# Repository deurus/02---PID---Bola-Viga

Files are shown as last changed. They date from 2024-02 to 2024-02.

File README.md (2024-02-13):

# Bola Viga

La maqueta está realizada con piezas impresas en 3D para la ocasión y un par de varillas metálicas por donde se desliza la bola.

El funcionamiento es muy sencillo, disponemos de un micro interruptor para cambiar entre modo manual y automático, y de un potenciómetro que en modo manual mueve el ángulo del servo y por ende la inclinación de la viga (OP), y en modo automático cambia el punto de consigna (SP) de posición de la bola en la viga. El objetivo es situar una bola en una posición determinada de la viga mediante un controlador PID.

<p align="center">
  esquema
</p>

Investigando un poco que tipo de sensores de distancia asequibles existen para Arduino, encontré unos cuantos y muchos ejemplos de uso, pero es diferente cuando se hace una prueba de un sensor a cuando le das un uso en el que se requiere cierta precisión. De todo lo que encontré me quedo con cuatro sensores de los que os dejo una tabla comparativa.

<p align="center">
  esquema
</p>

Tenéis más información en la entrada del blog: https://garikoitz.info/blog/2021/09/sintonizar-pid-con-arduino-sistema-bola-viga/

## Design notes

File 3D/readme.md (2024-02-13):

Los archivos 3D originales han sido creados por Henar Brenlla para su proyecto fin de grado que podéis encontrar aquí: [https://github.com/HenarB/controldedistanciapelota]

Autor: Henar Brenlla <br>
01 BASE SENSOR <br>		
02 BASE SERVO MOTOR <br>	
03 DISCO RANURADO <br>	
04 MANIVELA <br>	
05 SOPORTE SENSOR GP2Y0A21YK0F <br>
06 SOPORTE <br>

Autor: garikoitz.info <br>
05 SOPORTE SENSOR VL53L0X (Modificación para el sensor VL53L0X y varillas de otro diámetro)<br>
06 SOPORTE_v2 (Modificación del soporte original para varillas de otro diámetro)<br>

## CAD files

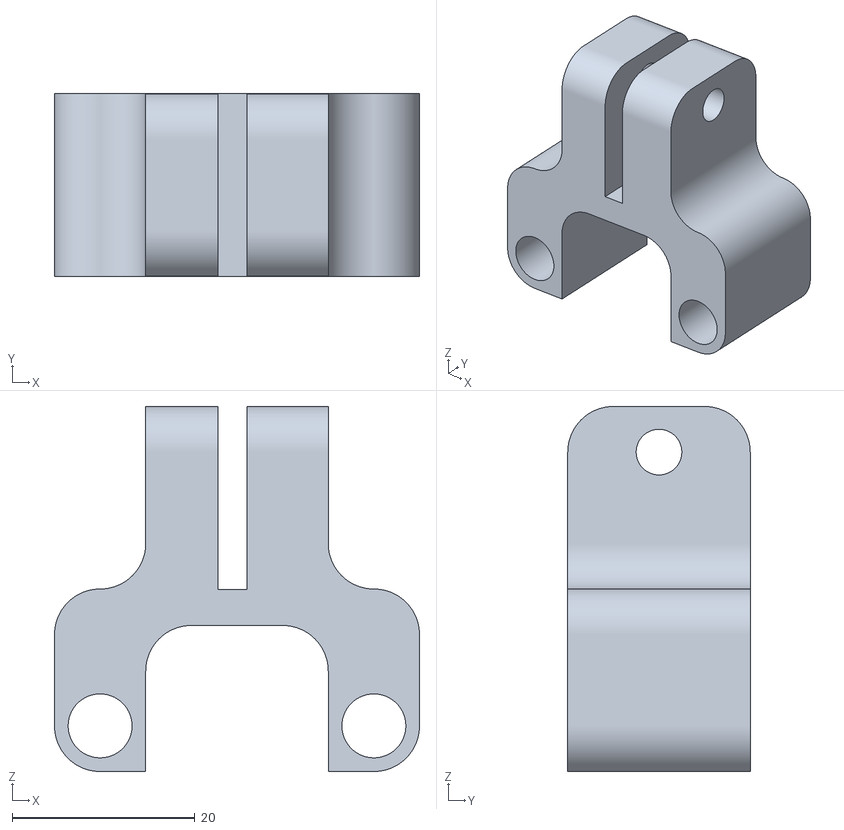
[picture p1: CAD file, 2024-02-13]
3D/06 SOPORTE_v3 (garikoitz).stl
40.0 x 20.0 x 40.0

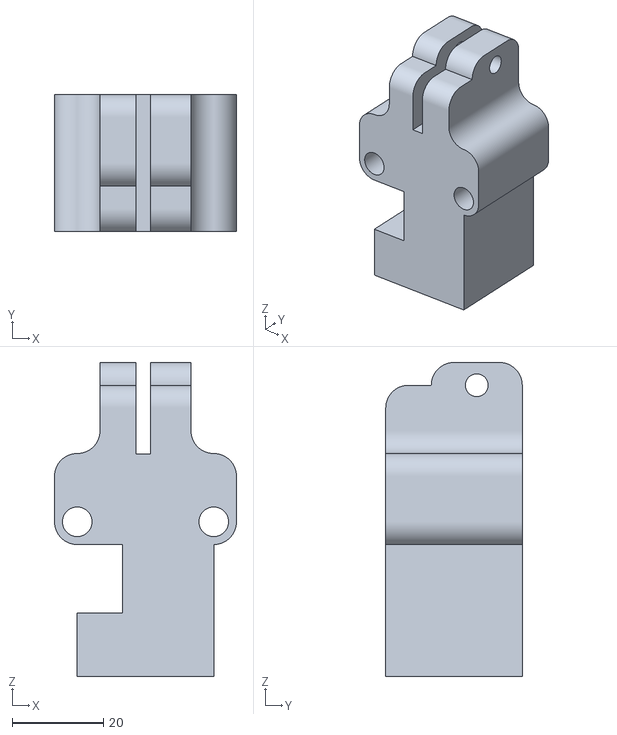
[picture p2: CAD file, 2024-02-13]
3D/05 SOPORTE SENSOR US-016_vertival_ (garikoitz).stl
40.0 x 30.0 x 69.0

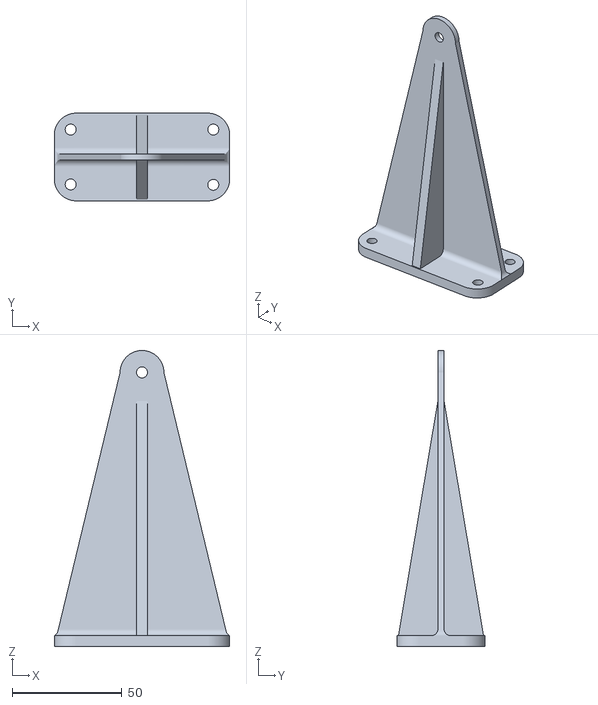
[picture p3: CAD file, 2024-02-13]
3D/01 BASE SENSOR.stl
80.0 x 40.0 x 135.0

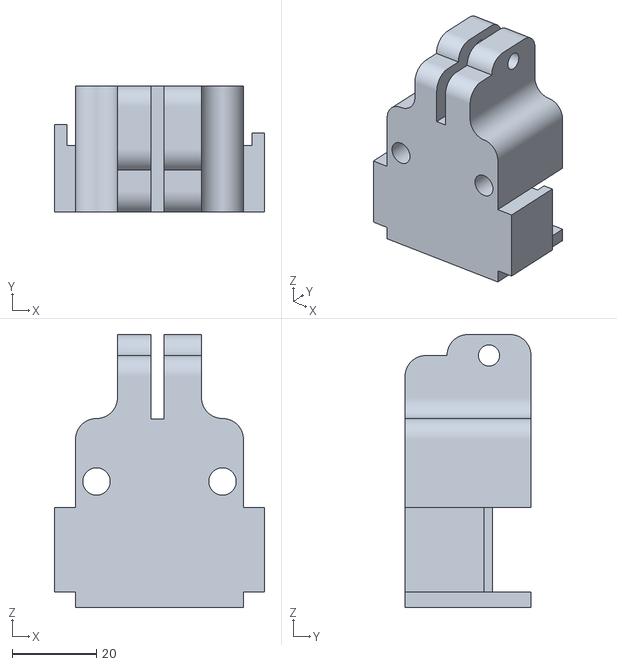
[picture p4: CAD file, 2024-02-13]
3D/05 SOPORTE SENSOR US-016_horizontal (garikoitz).stl
50.0 x 30.0 x 65.0

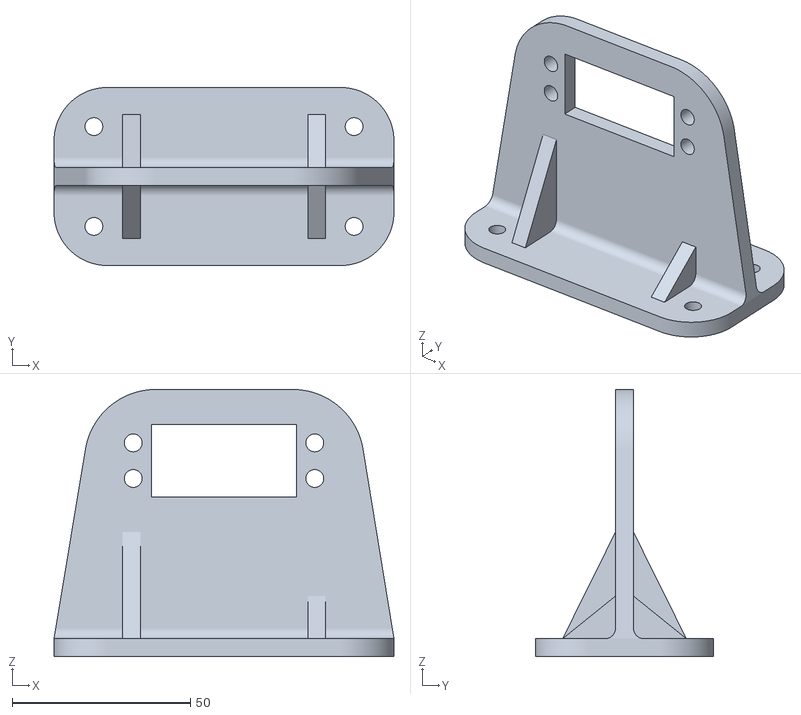
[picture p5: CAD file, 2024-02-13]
3D/02 BASE SERVO MOTOR.stl
95.5 x 50.0 x 75.0

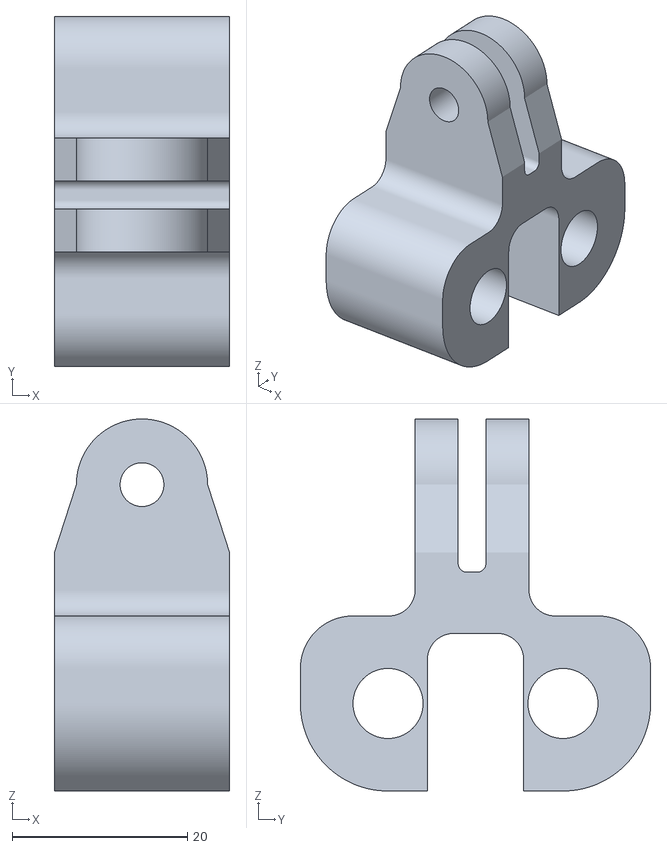
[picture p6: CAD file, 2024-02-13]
3D/06 SOPORTE.stl
20.0 x 40.0 x 42.5

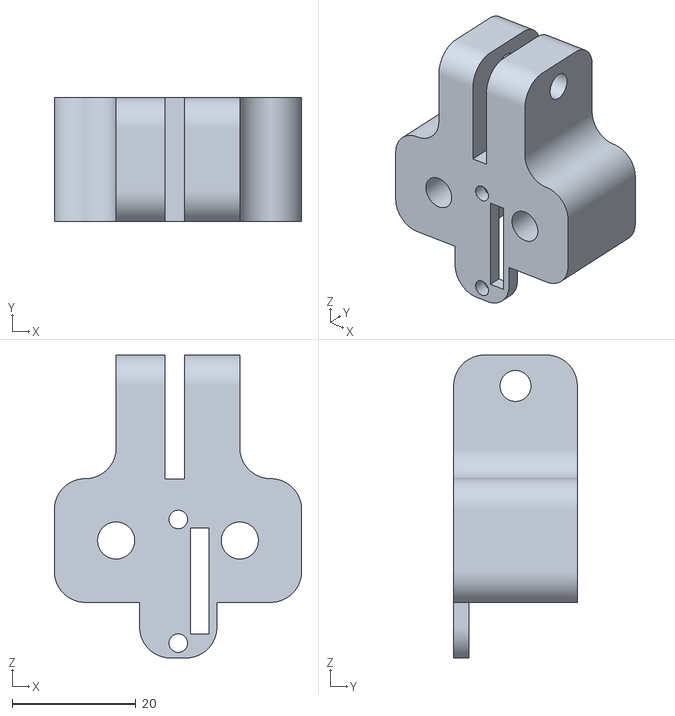
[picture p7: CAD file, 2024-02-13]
3D/05 SOPORTE SENSOR VL53L0X (garikoitz).stl
40.0 x 20.0 x 49.0

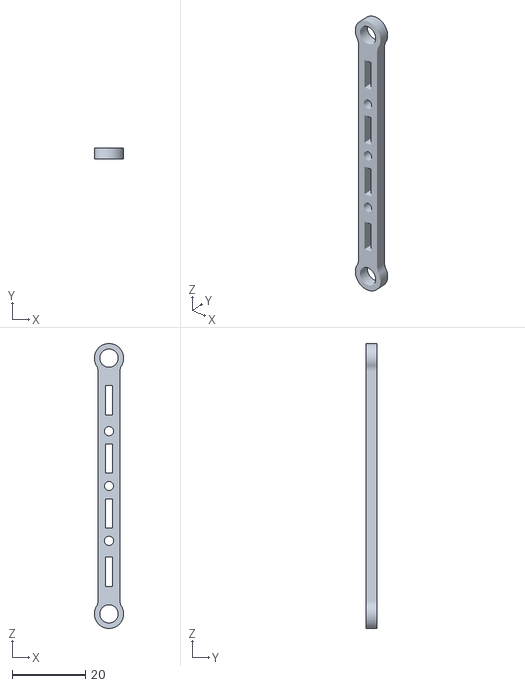
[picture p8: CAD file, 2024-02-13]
3D/04 MANIVELA.stl
8.00 x 3.00 x 78.0

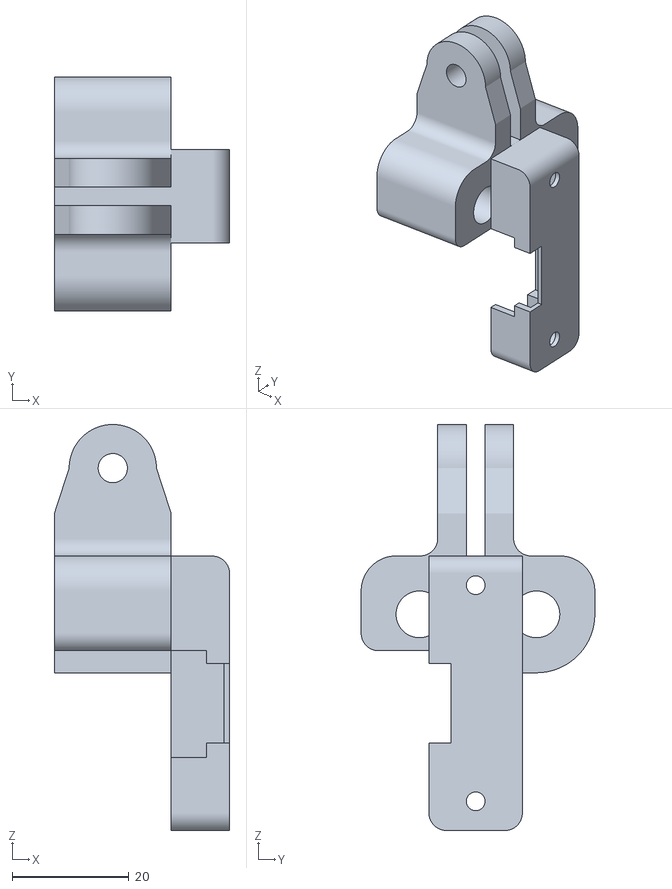
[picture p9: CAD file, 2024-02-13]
3D/05 SOPORTE SENSOR GP2Y0A21YK0F.stl
30.0 x 40.0 x 69.5

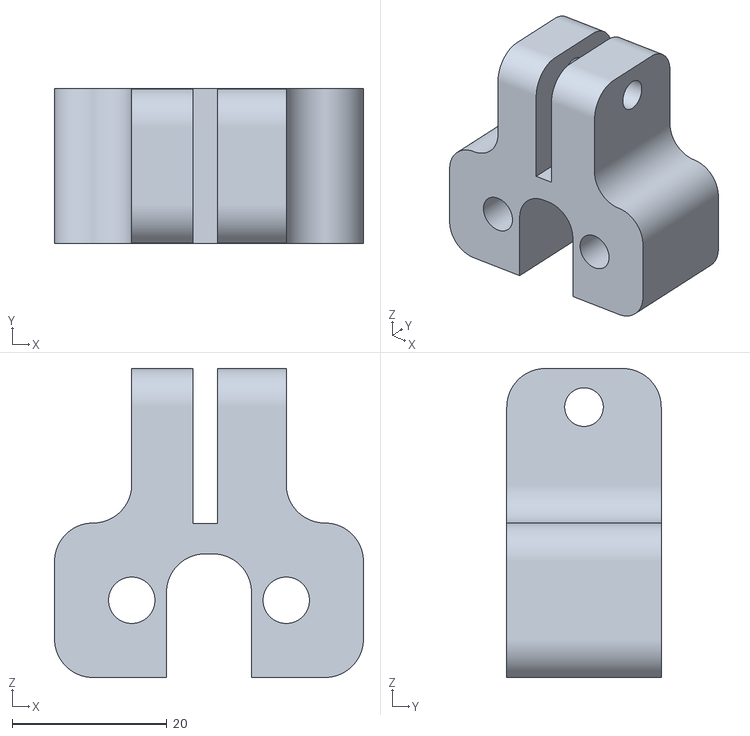
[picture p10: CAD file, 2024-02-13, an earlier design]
3D/06 SOPORTE_v2 (garikoitz).stl
40.0 x 20.0 x 40.0

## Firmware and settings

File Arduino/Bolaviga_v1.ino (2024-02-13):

/***************************************************************
* Desarrollado por Garikoitz Martínez [garikoitz.info] [06/2022]
* https://garikoitz.info/blog/?p=1301
***************************************************************/
/***************************************************************
* Librerías
***************************************************************/
#include <Wire.h>
#include <PID_v1.h>
#include "Adafruit_VL53L0X.h"
#include <Servo.h>
/***************************************************************
* Variables
***************************************************************/
Servo myservo;
const int Interruptor = 12;
unsigned long previousMillis = 0; 
int Ts = 50, pos = 0;
unsigned long contador = 0; 
//Control PID
boolean modo = false;                       //false=auto true=manual
float tmp=0.0, tmp_ant=0.0, OP=0, angulo=0.0, angulo_ant=0.0, media=0.0;
double SetpointP, InputP, OutputP;
/***************************************************************
* Sintonías calculadas (Relé --> Ku=0.99 y Tu=4.6 segundos)
***************************************************************/
//double Kc=0.59, Ki=0.26, Kd=0.34;   //Z-N classic PID
//double Kc=0.69, Ki=0.38, Kd=0.48;   //Z-N Pessen Integral Rule 
//double Kc=0.33, Ki=0.14, Kd=0.49;   //Z-N some overshoot
//double Kc=0.20, Ki=0.09, Kd=0.30;   //Z-N no overshoot
//double Kc=0.33, Ki=0.07, Kd=0.15;    //Farrington
//double Kc=0.49, Ki=0.11, Kd=0.57;    //Farrington
//double Kc=0.53, Ki=0.12, Kd=0.49;    //McAvoy and Johnson
//double Kc=0.25, Ki=0.07, Kd=0.28;    //Atkinson and Davey (20% overshoot)
//double Kc=0.99, Ki=0.43, Kd=0.57;    //Pettit and Carr (Underdamped)
//double Kc=0.66, Ki=0.14, Kd=0.50;    //Pettit and Carr (Critically damped)
//double Kc=0.49, Ki=0.07, Kd=0.38;    //Pettit and Carr (Overdamped)
//double Kc=0.44, Ki=0.16, Kd=0.38;    //Tinham (Less than quarter decay ratio response)
//double Kc=0.74, Ki=0.26, Kd=0.34;    //Corripio (Quarter decay ratio)
//double Kc=0.62, Ki=0.27, Kd=0.24;    //ABB (P+D tuning rule)
//double Kc=0.45, Ki=0.04, Kd=0.33;    //Tyreus and Luyben
//double Kc=0.33, Ki=0.14, Kd=0.19;    //Yu (Some overshoot)
//double Kc=0.20, Ki=0.09, Kd=0.11;    //Yu (No overshoot)
//double Kc=0.74, Ki=0.26, Kd=0.34;    //Smith
//double Kc=0.99, Ki=0.34, Kd=0.45;    //Alfaro Ruiz (Quarter decay ratio)
//double Kc=1.65, Ki=0.57, Kd=0.76;    //Alfaro Ruiz (Quarter decay ratio)
//double Kc=0.39, Ki=0.09, Kd=0.29;    //Lloyd (Non self-regulating processes)
//double Kc=0.59, Ki=0.26, Kd=0.33;    //NI Labview (Quarter decay ratio)
//double Kc=0.25, Ki=0.11, Kd=0.14;    //NI Labview (Some overshoot)
//double Kc=0.15, Ki=0.06, Kd=0.08;    //NI Labview (Little overshoot)
//---------------------------------------------------------------
double Kc=0.45, Ki=0.1, Kd=0.35;      //Tyreus and Luyben mod
//---------------------------------------------------------------
PID myPID(&InputP, &OutputP, &SetpointP, Kc, Ki, Kd,P_ON_E, REVERSE);//PI-D
//PID myPID(&InputP, &OutputP, &SetpointP, Kc, Ki, Kd,P_ON_M, REVERSE);  //I-PD
//
Adafruit_VL53L0X lox = Adafruit_VL53L0X();
/***************************************************************
* SETUP
***************************************************************/
void setup() 
{ 
  Wire.begin();
  if (!lox.begin()) {
    Serial.println(F("Error al conectar al sensor VL53L0X"));
    while(1);
  }
  lox.startRangeContinuous();
  myservo.attach(3); // asignamos el pin al servo.
  Serial.begin(9600);
  myPID.SetOutputLimits(0, 100);
  SetpointP = 70;
}
/***************************************************************
* BUCLE PRINCIPAL
***************************************************************/
void loop() 
{
  VL53L0X_RangingMeasurementData_t measure;
  lox.rangingTest(&measure, false);
  if (measure.RangeStatus != 4) {
    //media =  measure.RangeMilliMeter;
    media = Rolling_avg(measure.RangeMilliMeter);
    media = media * 0.1; //Pasamos a cm
  }
  if (millis() - previousMillis > Ts) //Bucle de control cada Ts milisegundos
  {
    previousMillis = millis();
    contador +=1;
    if (digitalRead(12) == HIGH){
      modo=true;                              //Modo Manual
      myPID.SetMode(MANUAL);
    }else{
      modo=false;                             //Modo Automático
      myPID.SetMode(AUTOMATIC);
    }
      InputP = mapf(media, 2, 26, 0, 100);    //PV en cm a porcentaje
      //InputP = media;
    /***************************************************************
    * Modo MANUAL - Potenciómetro ---> Ángulo Servo
    ***************************************************************/
    if (modo==true){
      //----------------------
      //   Método del Relé
      //----------------------
      if (1){
         if (InputP <60){
          pos=950;                       //arriba -> bola hacia la izq
          myservo.writeMicroseconds(pos);  
         }else if (InputP >60){     
          pos=1475;                       //abajo -> bola hacia la dcha
          myservo.writeMicroseconds(pos);  
         }
         OP = mapf(pos, 850, 1575, 0, 100);
      }
      //----------------------
      //     Potenciómetro 
      //----------------------
      if (0){
        SetpointP=0;
        tmp = analogRead(A1);
        tmp = mapf(tmp, 1023.0, 0.0, 850, 1575);        // escalamos potenciometro al servo
        if(abs(tmp-tmp_ant)>1){
          angulo = tmp;
        }
        tmp_ant=angulo;
        OP = mapf(tmp,850, 1575, 0, 100);
        if (angulo>=850 || angulo<=1575) myservo.writeMicroseconds(angulo);
      }   
      /***************************************************************
      * DEBUG PUERTO SERIE (Para Arduino COM Plotter)
      ***************************************************************/
      Serial.print("#");              //Char inicio
      Serial.print(0);                //SP
      Serial.write(" ");              //Char separador
      Serial.print(InputP,0);         //PV InputP
      Serial.write(" ");              //Char separador
      Serial.print(OP,0);             //OP
      Serial.println();
      }
      /***************************************************************
      * Modo AUTOMÁTICO - PID
      ***************************************************************/
      if (modo==false){
    if (0){  //SetPoint mediante Potenciómetro
      tmp = analogRead(A1);
      tmp = mapf(tmp, 0.0, 1023.0, 0, 100);
      if(abs(tmp-tmp_ant)>4){
        SetpointP = tmp;
      }
      tmp_ant=SetpointP;
    }
    if (1){
      // SetpointP automatizado
      if (contador < 1000) SetpointP = 70;  
      if (contador >= 1000 && contador < 2000) SetpointP = 60; 
      if (contador >= 2000 && contador < 3000) SetpointP = 50; 
      if (contador >= 3000 && contador < 4000) SetpointP = 60; 
      if (contador > 4000) contador = 0;
    }
        
        angulo = mapf(OutputP, 0, 100, 850, 1575);
    
        if (abs(SetpointP-InputP)>5){   //Banda muerta del 5%
          myPID.Compute();
          myservo.writeMicroseconds(angulo);
          angulo_ant = angulo;  
        }else{
          myservo.writeMicroseconds(angulo_ant); 
        }
    
        /***************************************************************
        * DEBUG PUERTO SERIE (Para Arduino COM Plotter)
        ***************************************************************/
        Serial.print("#");                //Char inicio
        Serial.print(SetpointP,0);        //SP
        Serial.write(" ");                //Char separador
        Serial.print(InputP,0);           //PV
        Serial.write(" ");                //Char separador
        Serial.print(OutputP,0);          //OP
        Serial.println();  
      }
  }//millis            
}//Loop
/***************************************************************
* FUNCIONES
***************************************************************/
//Función MAP adaptada a punto flotante.
double mapf(double val, double in_min, double in_max, double out_min, double out_max) {
    return (val - in_min) * (out_max - out_min) / (in_max - in_min) + out_min;
}
//High-pass Filter
    //A low α will be very slow to rapid input changes and take many samples into account. 
    //A high α will be fast, but average over fewer samples. You can look at α as kind of a cutoff frequency in a low-pass filter.
    //OP = HPS(tmp,0.1,EMA_s_pot);
    //OP = tmp-EMA_s_pot;
double HPS(double sensorValue, float EMA_a, int EMA_S) {
    return (EMA_a*sensorValue) + ((1-EMA_a)*EMA_S);
}
//Función Promedio
float Rolling_avg(float value) {
  const byte nvalues = 10;             // Moving average window size
  static byte current = 0;            // Index for current value
  static byte cvalues = 0;            // Count of values read (<= nvalues)
  static float sum = 0;               // Rolling sum
  static float values[nvalues];
  sum += value;
  if (cvalues == nvalues)
    sum -= values[current];
  values[current] = value;          // Replace the oldest with the latest
  if (++current >= nvalues)
    current = 0;
  if (cvalues < nvalues)
    cvalues += 1;
  return sum/cvalues;
}
